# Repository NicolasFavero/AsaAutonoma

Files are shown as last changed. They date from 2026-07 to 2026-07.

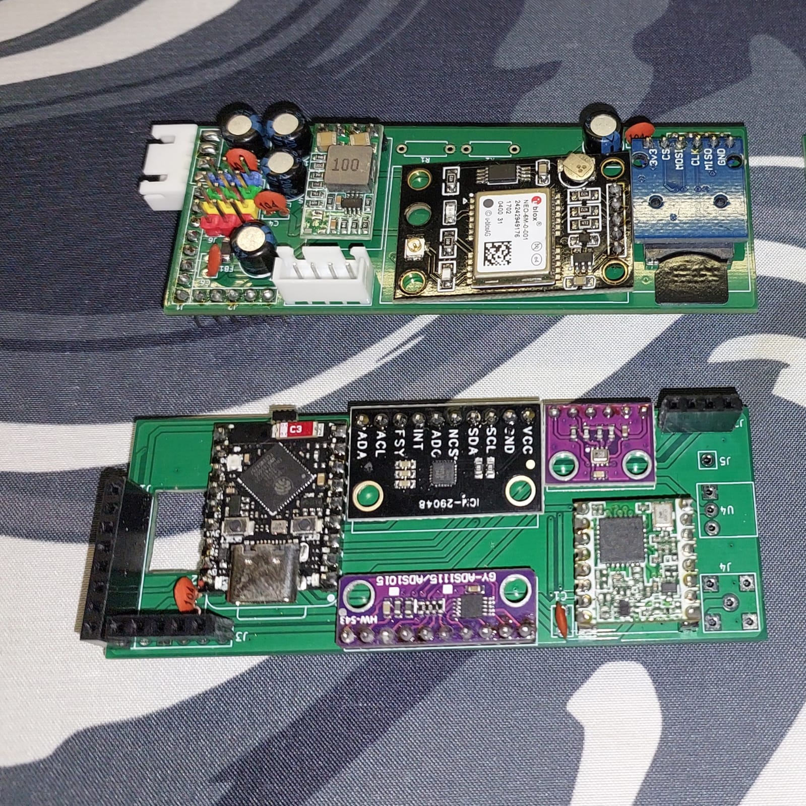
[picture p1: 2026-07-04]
media/image2.jpeg

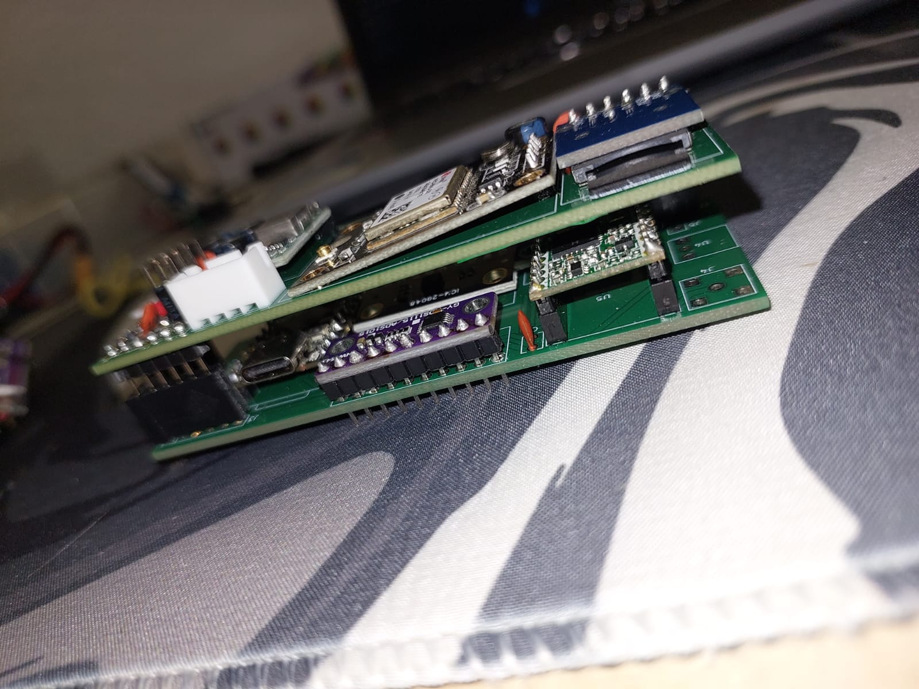
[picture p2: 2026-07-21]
media/image4.jpeg

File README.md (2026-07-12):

# Sistema de Controle e Telemetria para Aeromodelo Autônomo

## Sobre o projeto

Este projeto consiste no desenvolvimento de um **sistema embarcado de controle, navegação e telemetria para uma asa autônoma / aeromodelo planador experimental**.

O sistema é baseado em um **ESP32-S3** e tem como finalidade realizar a aquisição de dados de voo, processamento de sensores, controle das superfícies móveis da aeronave e armazenamento das informações para análise posterior.

O projeto encontra-se em fase de **protótipo e desenvolvimento**, sendo utilizado para testes de hardware, sensores, algoritmos de controle e integração de sistemas embarcados.

---

## Objetivo

Desenvolver uma plataforma experimental para estudo e implementação de um sistema de controle autônomo para aeronaves de pequeno porte, integrando:

* Sensoriamento inercial e ambiental;
* Controle eletrônico das superfícies de comando;
* Registro de dados de voo;
* Desenvolvimento de firmware embarcado;
* Testes e validação de sistemas aplicados à aviação experimental.

---

## Funcionalidades

* Leitura de sensores inerciais:

  * Aceleração;
  * Velocidade angular;
  * Campo magnético;
* Medição de altitude e pressão atmosférica utilizando BMP280;
* Leitura de velocidade do ar através de tubo de Pitot;
* Controle das superfícies de comando:

  * Leme;
  * Aileron;
  * Profundor;
* Controle de servomotores;
* Registro de dados de voo em cartão SD;
* Estrutura preparada para futuras expansões, como telemetria e algoritmos de controle autônomo.

---

## Status do projeto

🚧 **Protótipo em desenvolvimento**

O firmware e o hardware ainda estão em fase experimental. Alterações na arquitetura, sensores utilizados e funcionalidades podem ocorrer durante o desenvolvimento.

---

## Tecnologias utilizadas

### Hardware

* ESP32-S3 SuperMini;
* ICM-20948 (IMU 9DOF);
* BMP280 (pressão e altitude);
* Tubo de Pitot;
* Servomotores;
* Cartão SD.

### Software

* C / C++;
* PlatformIO;
* Arduino Framework.

---

## Dependências

```ini
lib_deps =
	sparkfun/SparkFun 9DoF IMU Breakout - ICM 20948 - Arduino Library@^1.3.2
	adafruit/Adafruit ADS1X15@^2.6.2
	adafruit/Adafruit BMP280 Library@^3.0.0
	mikalhart/TinyGPSPlus@^1.1.0
	greiman/SdFat@^2.3.1
	jgromes/RadioLib@^7.7.1
```

---

## Ambiente de desenvolvimento

* IDE: PlatformIO;
* Framework: Arduino;
* Placa alvo: ESP32-S3 SuperMini.

---

## Estrutura do projeto

```
Firmware/
├── src/
├── include/
├── lib/
└── platformio.ini
```

---

## Aplicação

Projeto desenvolvido para fins educacionais e experimentais, integrando conhecimentos de **eletrônica, programação embarcada, sensores, controle e sistemas aeronáuticos** dentro de uma formação técnica em eletrônica.

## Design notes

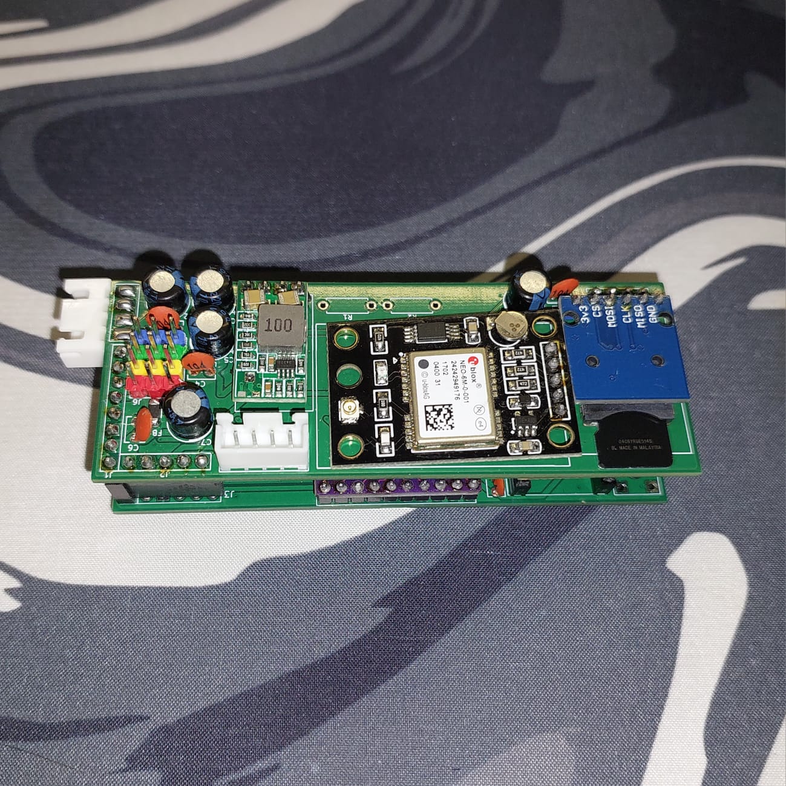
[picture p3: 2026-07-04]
Firmware/midia/midia2.jpeg

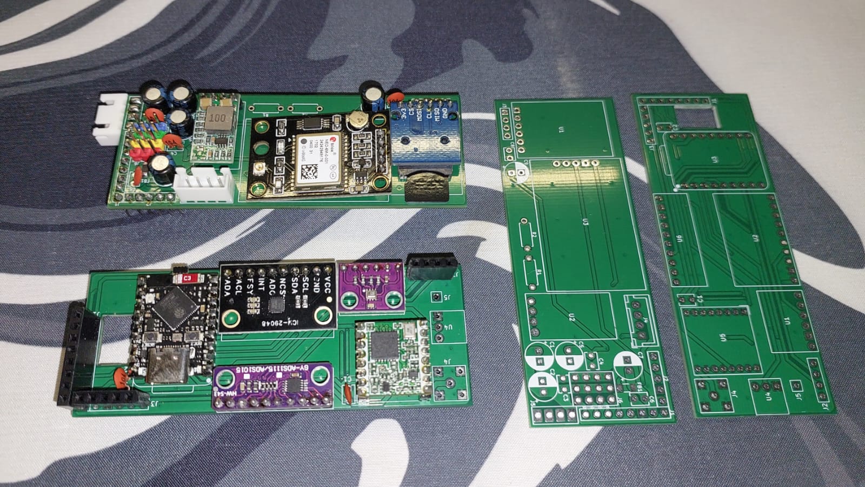
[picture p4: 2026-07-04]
Firmware/midia/midia4.jpeg

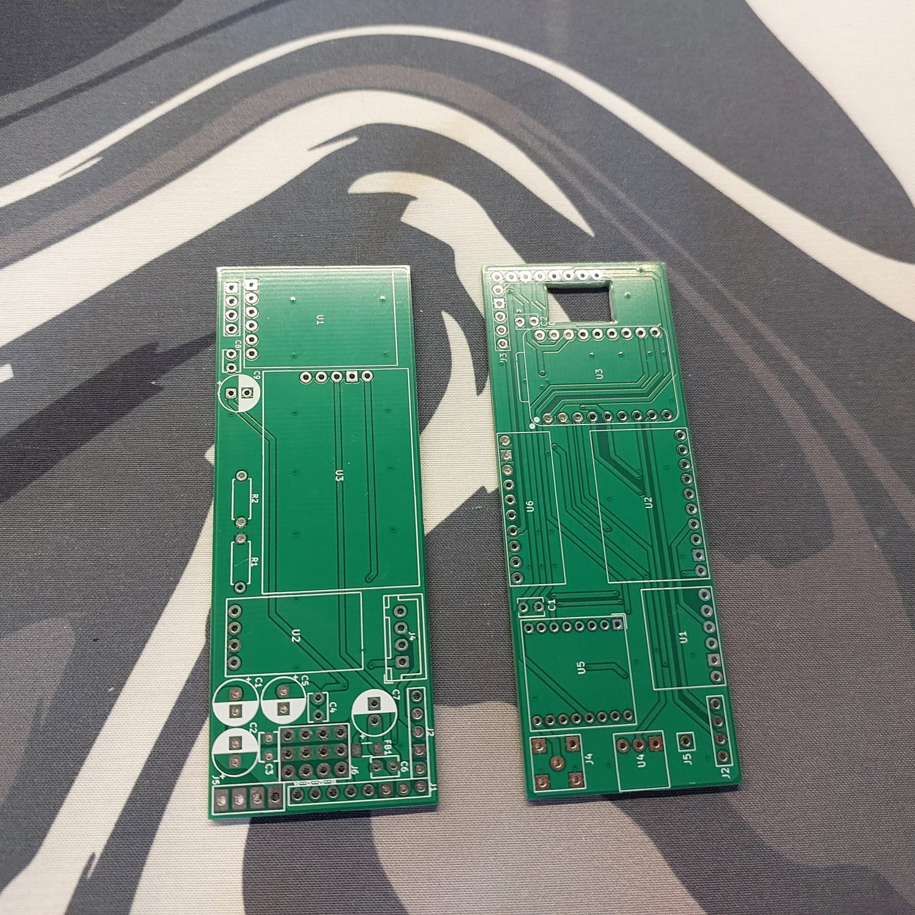
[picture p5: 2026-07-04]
Firmware/midia/midia3.jpeg

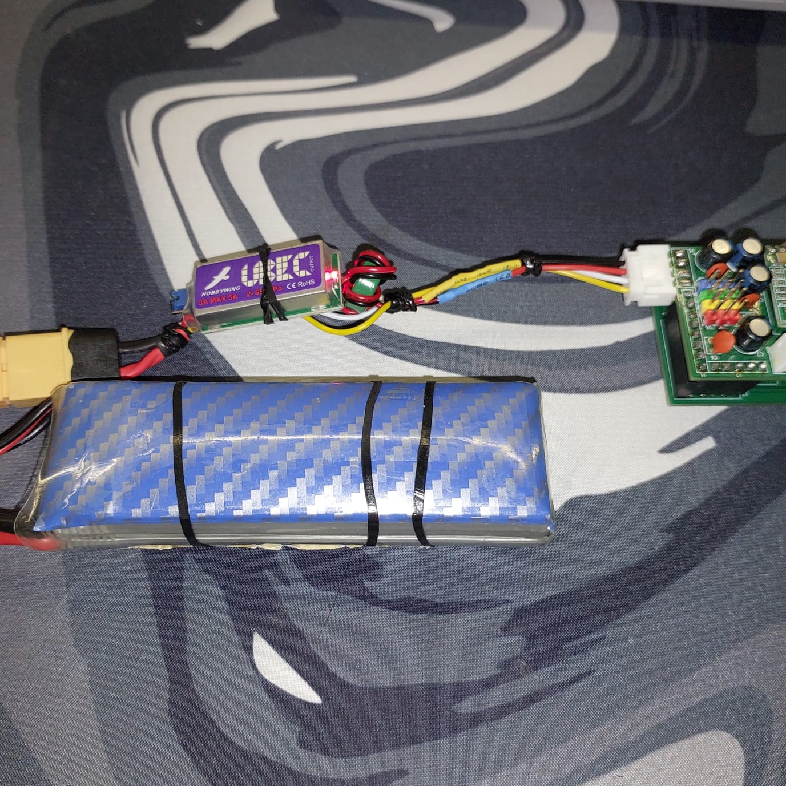
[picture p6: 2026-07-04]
Firmware/midia/midia5.jpeg

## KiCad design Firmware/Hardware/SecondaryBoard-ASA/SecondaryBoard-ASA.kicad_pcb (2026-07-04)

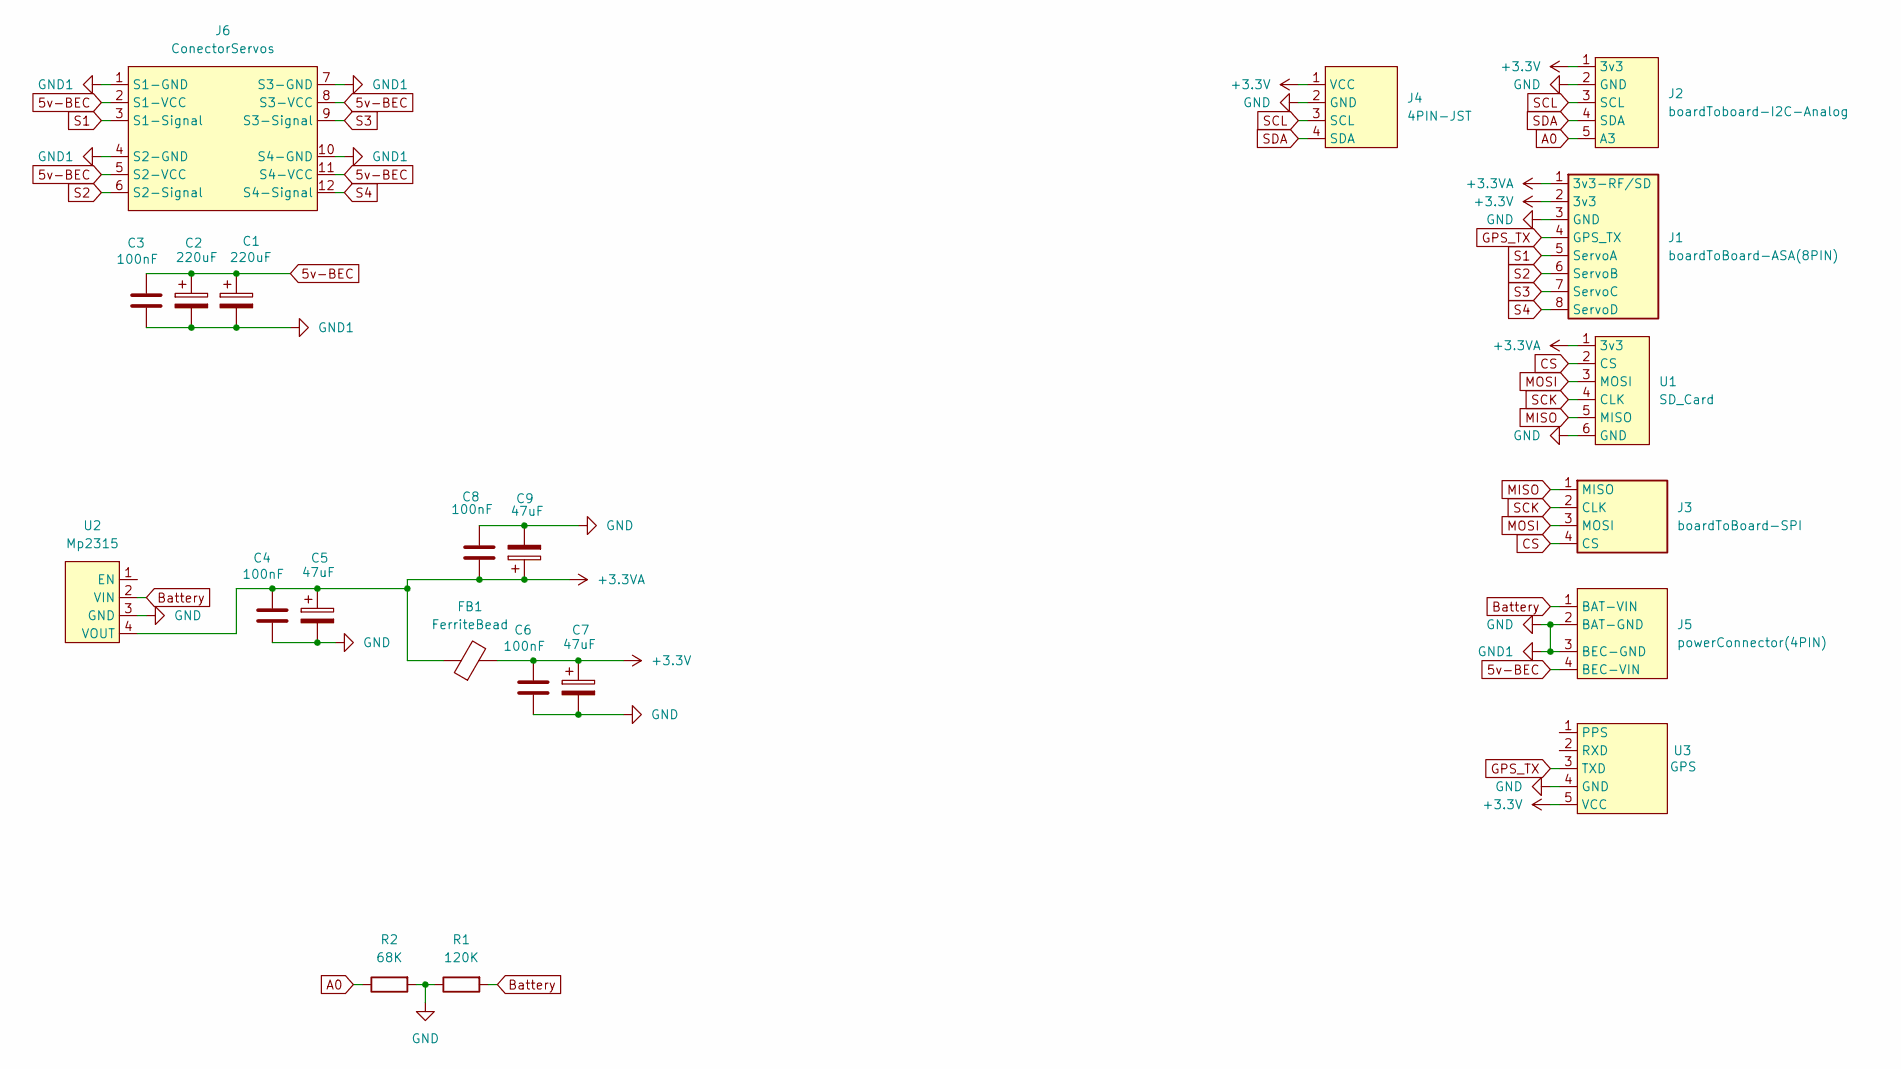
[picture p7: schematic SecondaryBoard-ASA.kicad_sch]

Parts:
C1, C2: 220uF; CP_Radial_D6.3mm_P2.50mm
C3, C4, C6, C8: 100nF; C_Disc_D3.8mm_W2.6mm_P2.50mm
C5, C7, C9: 47uF; CP_Radial_D6.3mm_P2.50mm
FB1: FerriteBead; R_1206_3216Metric_Pad1.30x1.75mm_HandSolder
J1: boardToBoard-ASA(8PIN); PinSocket_1x08_P2.54mm_Vertical
J2: boardToboard-I2C-Analog; PinHeader_1x05_P2.54mm_Vertical
J3: boardToBoard-SPI; PinHeader_1x04_P2.54mm_Vertical
J4: 4PIN-JST; JST_XH_B4B-XH-A_1x04_P2.50mm_Vertical
J5: powerConnector(4PIN); ConnectorBaterry+BEC
J6: ConectorServos; 4Servos
R1: 120K; R_Axial_DIN0207_L6.3mm_D2.5mm_P7.62mm_Horizontal
R2: 68K; R_Axial_DIN0207_L6.3mm_D2.5mm_P7.62mm_Horizontal
U1: SD_Card
U2: Mp2315
U3: GPS

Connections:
5v-BEC: C1.1, C2.1, C3.1, J5.4 (BEC-VIN), J6.2 (S1-VCC), J6.5 (S2-VCC), J6.8 (S3-VCC), J6.11 (S4-VCC)
+3.3V: C6.1, C7.1, FB1.2, J1.2 (3v3), J2.1 (3v3), J4.1 (VCC), U3.5 (VCC)
+3.3VA: C4.1, C5.1, C8.1, C9.1, FB1.1, J1.1 (3v3-RF/SD), U1.1 (3v3), U2.4 (VOUT)
A0: J2.5 (A3), R2.1
Battery: J5.1 (BAT-VIN), R1.2, U2.2 (VIN)
CS: J3.4 (CS), U1.2 (CS)
GND: C1.2, C2.2, C3.2, C4.2, C5.2, C6.2, C7.2, C8.2, C9.2, J1.3 (GND), J2.2 (GND), J4.2 (GND), J5.2 (BAT-GND), J5.3 (BEC-GND), J6.1 (S1-GND), J6.4 (S2-GND), J6.7 (S3-GND), J6.10 (S4-GND), R1.1, R2.2, U1.6 (GND), U2.3 (GND), U3.4 (GND)
GPS_TX: J1.4 (GPS_TX), U3.3 (TXD)
MISO: J3.1 (MISO), U1.5 (MISO)
MOSI: J3.3 (MOSI), U1.3 (MOSI)
S1: J1.5 (ServoA), J6.3 (S1-Signal)
S2: J1.6 (ServoB), J6.6 (S2-Signal)
S3: J1.7 (ServoC), J6.9 (S3-Signal)
S4: J1.8 (ServoD), J6.12 (S4-Signal)
SCK: J3.2 (CLK), U1.4 (CLK)
SCL: J2.3 (SCL), J4.3 (SCL)
SDA: J2.4 (SDA), J4.4 (SDA)

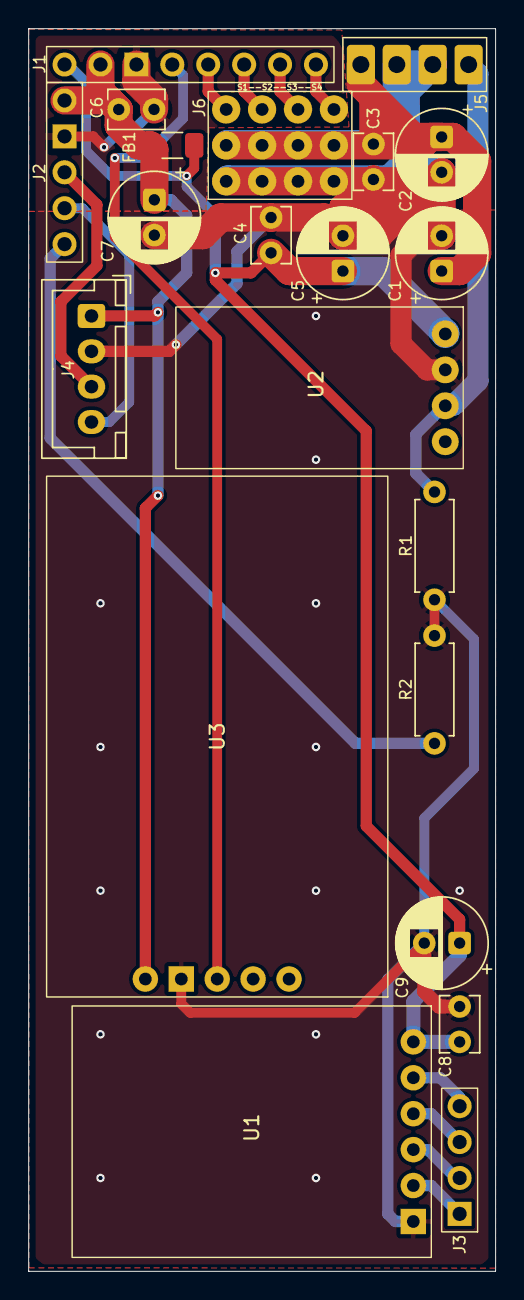
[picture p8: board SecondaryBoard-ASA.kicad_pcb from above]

Board: 2 copper layers, 33.0 x 87.9 mm, 21 parts (0 on the bottom side), 17 nets.

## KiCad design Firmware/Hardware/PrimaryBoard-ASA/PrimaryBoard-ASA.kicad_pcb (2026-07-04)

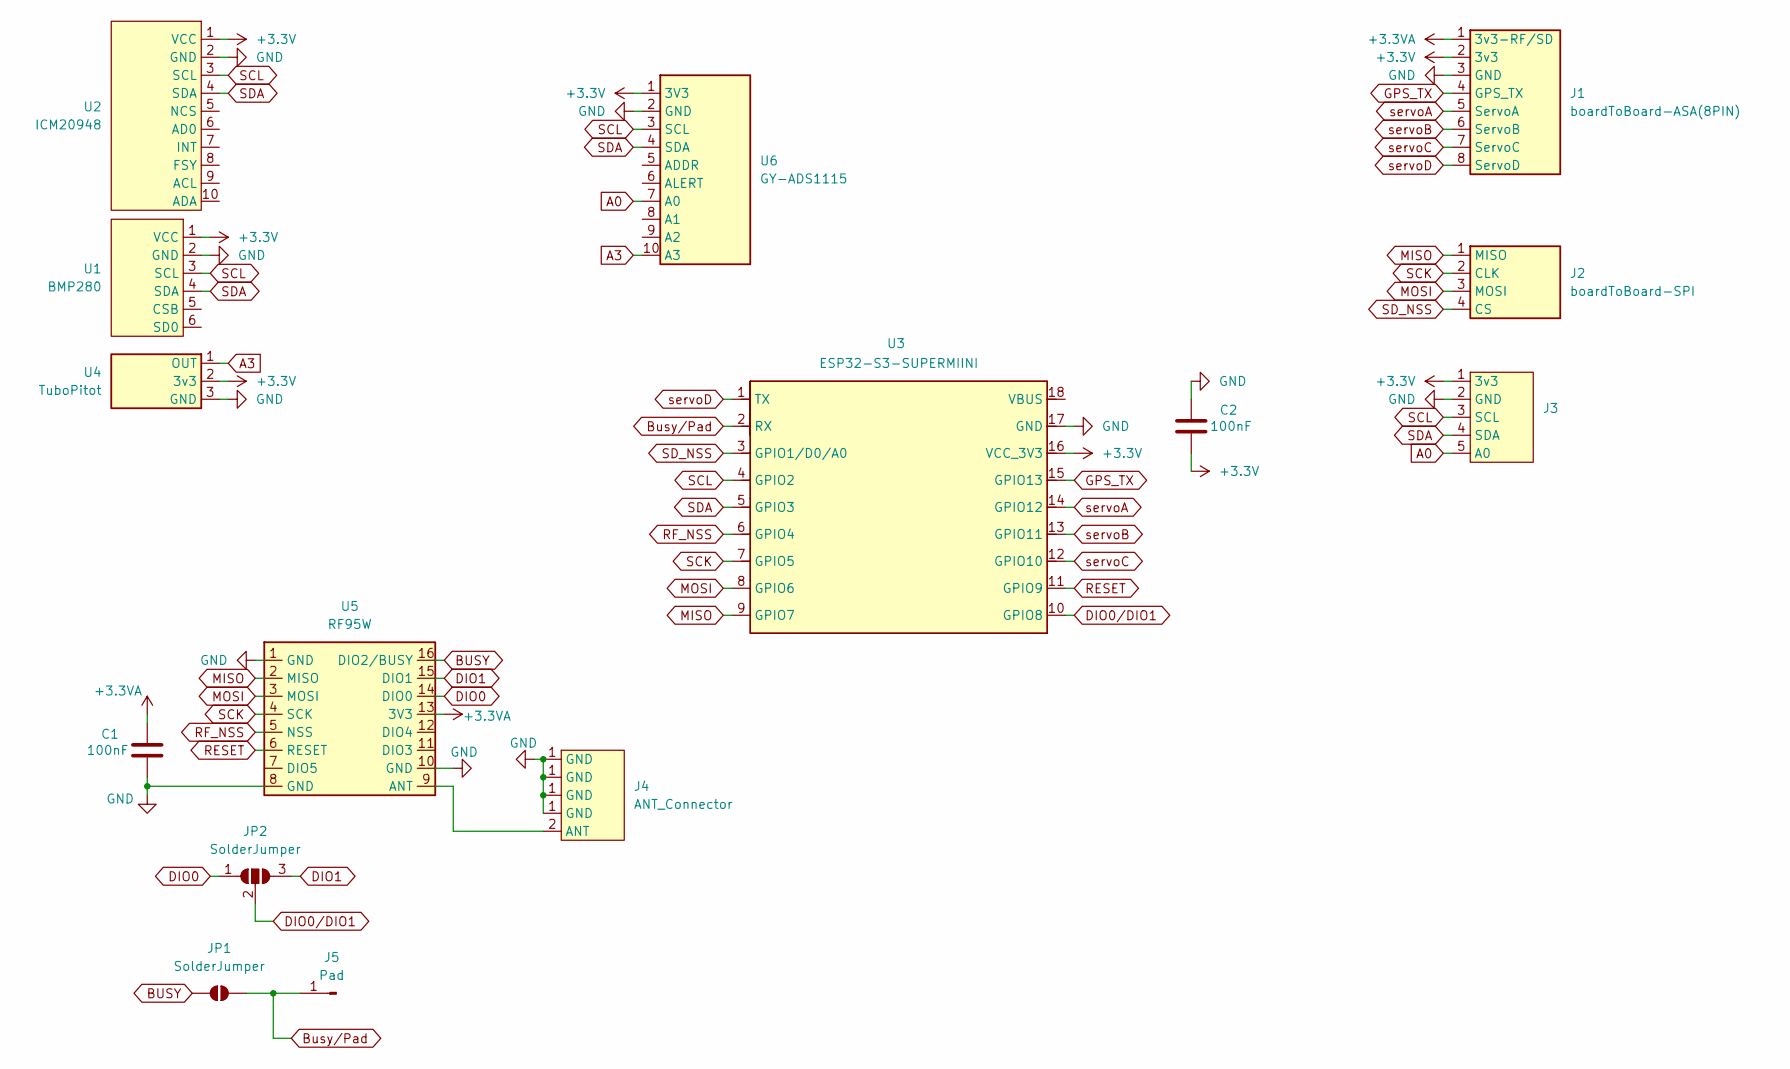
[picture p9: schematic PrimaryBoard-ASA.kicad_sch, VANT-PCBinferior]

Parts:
C1, C2: 100nF; C_Disc_D3.8mm_W2.6mm_P2.50mm
J1: boardToBoard-ASA(8PIN); PinHeader_1x08_P2.54mm_Vertical
J2: boardToBoard-SPI; PinHeader_1x04_P2.54mm_Vertical
J3: PinHeader_1x05_P2.54mm_Vertical
J4: ANT_Connector; conectorAntena2.54mm
J5: Pad; PinHeader_1x01_P2.54mm_Vertical
JP1: SolderJumper; SolderJumper-2_P1.3mm_Open_RoundedPad1.0x1.5mm
JP2: SolderJumper; SolderJumper-3_P1.3mm_Open_RoundedPad1.0x1.5mm
U1: BMP280
U2: ICM20948; ICM 20948
U3: ESP32-S3-SUPERMIINI; myEsp32-S3-Mini
U4: TuboPitot; tuboPitot
U5: RF95W; rf96w
U6: GY-ADS1115; ads1115

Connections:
+3.3V: C2.1, J1.2 (3v3), J3.1 (3v3), U1.1 (VCC), U2.1 (VCC), U3.16 (VCC_3V3), U4.2 (3v3), U6.1 (3V3)
+3.3VA: C1.2, J1.1 (3v3-RF/SD), U5.13 (3V3)
A0: J3.5 (A0), U6.7 (A0)
A3: U4.1 (OUT), U6.10 (A3)
BUSY: JP1.1 (A), U5.16 (DIO2/BUSY)
Busy/Pad: J5.1, JP1.2 (B), U3.2 (RX)
DIO0: JP2.1 (A), U5.14 (DIO0)
DIO0/DIO1: JP2.2 (C), U3.10 (GPIO8)
DIO1: JP2.3 (B), U5.15 (DIO1)
GND: C1.1, C2.2, J1.3 (GND), J3.2 (GND), J4.1 (GND), U1.2 (GND), U2.2 (GND), U3.17 (GND), U4.3 (GND), U5.1 (GND), U5.8 (GND), U5.10 (GND), U6.2 (GND)
GPS_TX: J1.4 (GPS_TX), U3.15 (GPIO13)
MISO: J2.1 (MISO), U3.9 (GPIO7), U5.2 (MISO)
MOSI: J2.3 (MOSI), U3.8 (GPIO6), U5.3 (MOSI)
unnamed: J4.2 (ANT), U5.9 (ANT)
RESET: U3.11 (GPIO9), U5.6 (RESET)
RF_NSS: U3.6 (GPIO4), U5.5 (NSS)
SCK: J2.2 (CLK), U3.7 (GPIO5), U5.4 (SCK)
SCL: J3.3 (SCL), U1.3 (SCL), U2.3 (SCL), U3.4 (GPIO2), U6.3 (SCL)
SDA: J3.4 (SDA), U1.4 (SDA), U2.4 (SDA), U3.5 (GPIO3), U6.4 (SDA)
SD_NSS: J2.4 (CS), U3.3 (GPIO1/D0/A0)
servoA: J1.5 (ServoA), U3.14 (GPIO12)
servoB: J1.6 (ServoB), U3.13 (GPIO11)
servoC: J1.7 (ServoC), U3.12 (GPIO10)
servoD: J1.8 (ServoD), U3.1 (TX)

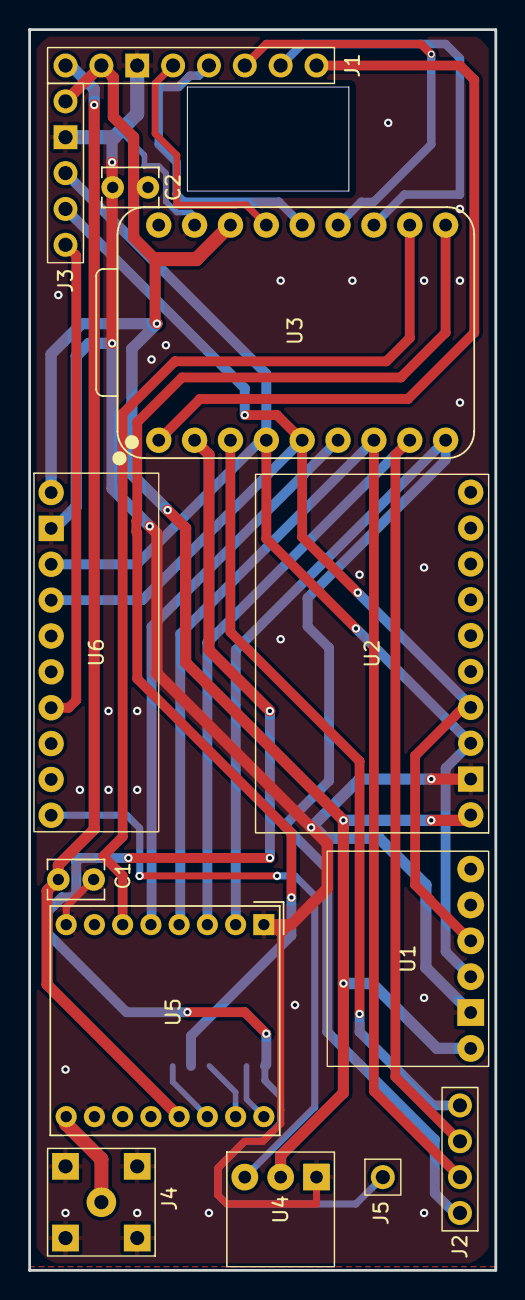
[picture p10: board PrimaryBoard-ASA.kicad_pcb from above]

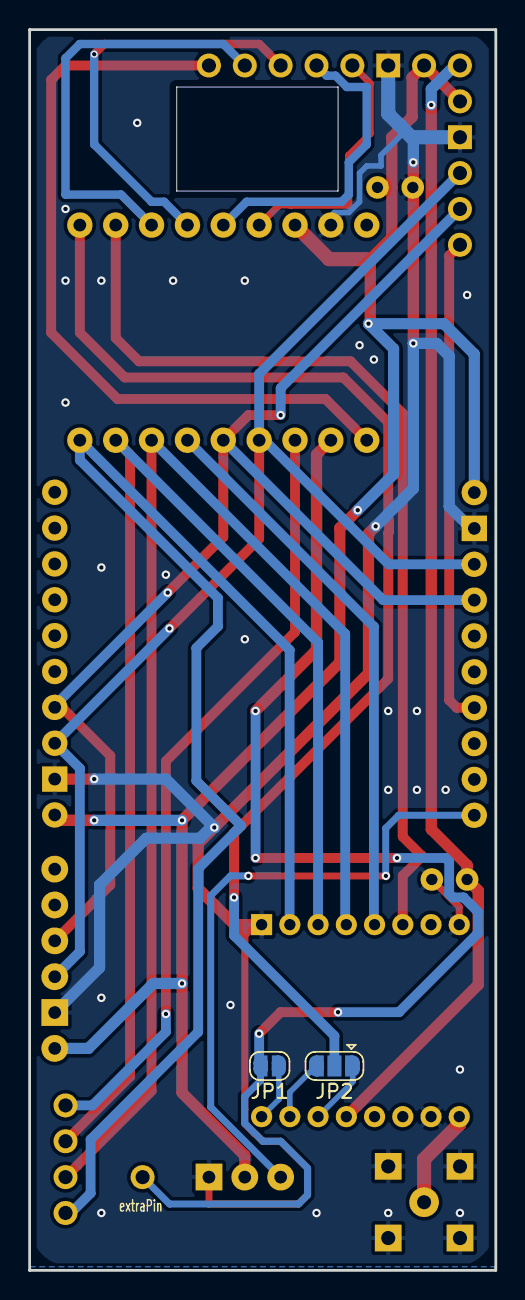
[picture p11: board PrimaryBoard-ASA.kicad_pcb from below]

Board: 2 copper layers, 33.0 x 87.9 mm, 15 parts (2 on the bottom side), 24 nets.

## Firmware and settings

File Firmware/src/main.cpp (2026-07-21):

// Arduino
#include "Arduino.h"

// Config
#include "Pins.h"
#include "ServomotorConfig.h"
#include "DataTypes.h"
#include "CurrentConfig.h"

// Drivers
#include "IMU.h"
#include "GPS.h"
#include "BMP280.h"
#include "ADS1X15.h"

// Communication
#include "RF96W.h"
#include "WiFiAP.h"

// Storage
#include "SdLogger.h"
#include "PreferencesManager.h"

// Control
#include "PID.h"
#include "Servo.h"

// Telemetry
#include "Telemetry.h" //ALTEREI PRA DEBUG     float pitch = imuValid ? attitude.pitch : 0.0f; LEMBRAR DE VOLTAR ATRAS DEPOIS!!!!!!!!!!!!!!!

// Debug
#include "Led.h"
//=======================================================================================================================================================
//OTHERS
unsigned long lastTelemetryMillis = 0;
unsigned long countdownStartMillis = 0;
constexpr unsigned long COUNTDOWN_DURATION_MS = 10000; // mesmo valor do COUNTDOWN_DURATION_S no script.js
volatile bool newOffsetsAvailable = false;
volatile bool newPidAvailable = false;

bool wifiEnabled = false;
bool wifiTemporary = false;

unsigned long wifiStartMillis = 0;
//==================================================================STRUCTS===============================================================================
ImuOffsets currentOffsets; 
PidConfig currentPidConfig;
SystemConfig systemConfig;
SystemStatus systemStatus;
//========================================================================================================================================================
//==================================================================CLASSES==============================================================================
// Drivers
IMU imu;
ADS ads;
BMP280 bmp;
GPS gps(Pins::GPS_TX);

// Communication
LoRa lora(Pins::LORA_CS, Pins::LORA_DIO0, Pins::LORA_RESET, systemConfig.lora);
WifiAP wifi;

// Storage
SdLogger sd(Pins::SD_CS);
PreferencesManager nvs;

// Control
PID pid;

// Actuators
Servo elevator    (Pins::ELEVATOR,      ServoConfig::Channel::ELEVATOR,      ServoConfig::FREQUENCY, ServoConfig::RESOLUTION);
Servo leftAlieron (Pins::LEFT_AILERON,  ServoConfig::Channel::LEFT_AILERON,  ServoConfig::FREQUENCY, ServoConfig::RESOLUTION);
Servo rightAlieron(Pins::RIGHT_AILERON, ServoConfig::Channel::RIGHT_AILERON, ServoConfig::FREQUENCY, ServoConfig::RESOLUTION);
//Servo rudder    (Pins::RUDDER,        ServoConfig::Channel::RUDDER,        ServoConfig::FREQUENCY, ServoConfig::RESOLUTION); 

// Telemetry
Telemetry telemetry;

//Visual Debug
Led led;

//========================================================================================================================================================
//==============================================================FREEERTOS QUEUES===============================================================================
QueueHandle_t attitudeQueue;
QueueHandle_t navigationQueue;
portMUX_TYPE offsetMux = portMUX_INITIALIZER_UNLOCKED;
portMUX_TYPE pidMux = portMUX_INITIALIZER_UNLOCKED;
//========================================================================================================================================================
//=================================================================PROTOTYPES=============================================================================
// TASKS
void taskControl(void *pv);
void taskData(void *pv);

// TASK CONTROL HELPERS
bool readAttitudeData(AttitudeData& attitude);

// TASK DATA HELPERS
void sendNavigationData(NavigationData& navigationData);
void handleWifiTimeout();
void handleOutputs(FlightMode mode);
void handleWifi(const AttitudeData& attitude, const NavigationData& navigationData);
void updateGpsStatus();
void setupWifi();
TelemetryData buildTelemetryData(AttitudeData& attitude);
// GENERAL HELPERS
bool isLowPowerModeEnabled();

//=========================================================================================================================================================
//===================================================================SETUP=================================================================================
void setup(){
  Serial.begin(115200);
  Serial.println("Beginning...");
  Wire.begin(Pins::SDA, Pins::SCL);
  Wire.setClock(400000); 

  SPI.begin(Pins::SCK, Pins::MISO, Pins::MOSI);

  led.white();
  //led.white();

  nvs.loadSystem(systemConfig);
  nvs.loadOffsets(currentOffsets);
  nvs.loadPid(currentPidConfig);

  // Sem isso, o offset salvo nas Preferences so era realmente
  // aplicado no calculo do angulo (localOffsets, dentro da task de
  // controle) depois que o usuario salvasse um offset pela web --
  // ate la, localOffsets ficava zerado mesmo com currentOffsets/
  // /api/status ja reportando o valor salvo do boot anterior. Isso
  // fazia a primeira tara depois de ligar somar o offset antigo (que
  // NAO estava de fato sendo subtraido da leitura) com o novo valor
  // calculado, dando um offset errado logo na primeira vez -- so
  // acertava no segundo, quando o evento OFFSET_CHANGED sincronizava
  // localOffsets pela primeira vez. Marcando newOffsetsAvailable aqui,
  // a task de controle sincroniza localOffsets = currentOffsets logo
  // na primeira iteracao do loop, antes de qualquer leitura ser usada.
  newOffsetsAvailable = true;

  pid.pitch.kp = currentPidConfig.pitch.kp;
  pid.pitch.ki = currentPidConfig.pitch.ki;
  pid.pitch.kd = currentPidConfig.pitch.kd;

  pid.roll.kp = currentPidConfig.roll.kp;
  pid.roll.ki = currentPidConfig.roll.ki;
  pid.roll.kd = currentPidConfig.roll.kd;

  pid.yaw.kp = currentPidConfig.yaw.kp;
  pid.yaw.ki = currentPidConfig.yaw.ki;
  pid.yaw.kd = currentPidConfig.yaw.kd;

  while(!imu.begin()){led.red();}
  while(!bmp.begin()){led.red();}
  while(!gps.begin()){led.red();}
  while(!ads.begin()){led.red();}
  while(!lora.begin()){led.red();}

  while(!elevator.begin()){led.red();}
  while(!leftAlieron.begin()){led.red();}
  while(!rightAlieron.begin()){led.red();}


  while(!sd.begin()) {Serial.println("SD FAIL"); led.red();}

  // Buffer em RAM/PSRAM pros logs de voo -- ver comentarios em
  // SdLogger::beginBuffer()/bufferLine(). Se falhar (placa sem PSRAM
  // ou sem RAM livre suficiente), o firmware continua funcionando,
  // so volta a escrever direto no SD a cada leitura como antes.
  sd.beginBuffer();

  attitudeQueue = xQueueCreate(1, sizeof(AttitudeData));
  navigationQueue = xQueueCreate(1, sizeof(NavigationData));

  if(attitudeQueue == NULL || navigationQueue == NULL){
    while(true){
      led.red();
      delay(500);
    }
  }
  setupWifi();

  lastTelemetryMillis = millis();

  led.green();
  
  xTaskCreatePinnedToCore(
    taskControl,
    "Control",
    10000,
    NULL,
    2,
    NULL,
    0
  );
  xTaskCreatePinnedToCore(
    taskData,
    "Data",
    10000,
    NULL,
    1,
    NULL,
    1
  );
}
//==========================================================================================================================================================
//================================================================KILLING TASK==============================================================================
void loop(){vTaskDelete(NULL);}
//==========================================================================================================================================================
//=================================================================TASK AT CORE 0===========================================================================
void taskControl(void *pv){

  TickType_t lastWake = xTaskGetTickCount();
  const TickType_t period = pdMS_TO_TICKS(5); //200HZ

  while(true){
    bool useNewValues = true;

    static AttitudeData attitudeData;
    static NavigationData nav; 
    static ServoPositions angle;
    static ImuOffsets localOffsets; 
  //===================TO  ATTITUDE==============
    if(systemConfig.flightMode == FlightMode::CONFIG && newOffsetsAvailable){
      portENTER_CRITICAL(&offsetMux);

      localOffsets = currentOffsets;

      newOffsetsAvailable = false;

      portEXIT_CRITICAL(&offsetMux);
    }

    if(systemConfig.flightMode == FlightMode::CONFIG && newPidAvailable){
      portENTER_CRITICAL(&pidMux);

      pid.pitch.kp = currentPidConfig.pitch.kp;
      pid.pitch.ki = currentPidConfig.pitch.ki;
      pid.pitch.kd = currentPidConfig.pitch.kd;

      pid.roll.kp = currentPidConfig.roll.kp;
      pid.roll.ki = currentPidConfig.roll.ki;
      pid.roll.kd = currentPidConfig.roll.kd;

      pid.yaw.kp = currentPidConfig.yaw.kp;
      pid.yaw.ki = currentPidConfig.yaw.ki;
      pid.yaw.kd = currentPidConfig.yaw.kd;

      newPidAvailable = false;

      portEXIT_CRITICAL(&pidMux);
    }

    imu.update();

    if(systemConfig.flightMode == FlightMode::FLIGHT){
      pid.setAngles(angle, attitudeData, nav, useNewValues);
    }


    elevator.write(angle.elevator);
    leftAlieron.write(angle.leftAileron);
    rightAlieron.write(angle.rightAileron);

  //===================TO  ATTITUDE==============
  //=====================FOR SEND================
    attitudeData.pitch = imu.getPitch() - localOffsets.pitch;
    attitudeData.roll = imu.getRoll() - localOffsets.roll;
    attitudeData.yaw = imu.getYaw() - localOffsets.yaw;

    // Mesmo valor que acabou de ir pro elevator.write()/leftAlieron.write()/
    // rightAlieron.write() acima -- registrado aqui, e nao lido de volta do
    // servo, porque servo (PWM) nao tem telemetria de posicao real.
    attitudeData.servoElevator = angle.elevator;
    attitudeData.servoLeftAileron = angle.leftAileron;
    attitudeData.servoRightAileron = angle.rightAileron;

    attitudeData.accX = imu.getAccX();
    attitudeData.accY = imu.getAccY();
    attitudeData.accZ = imu.getAccZ();

    attitudeData.gyroX = imu.getGyroX();
    attitudeData.gyroY = imu.getGyroY();
    attitudeData.gyroZ = imu.getGyroZ();

    attitudeData.magX= imu.getMagX();
    attitudeData.magY = imu.getMagY();
    attitudeData.magZ = imu.getMagZ();

    attitudeData.isImuOk = imu.isHealthy();

    xQueueOverwrite(attitudeQueue, &attitudeData);
  //=====================FOR SEND================
  //====================TO  RECEIVE==============
    if(xQueueReceive(navigationQueue,&nav,0)){useNewValues = true;}
  //====================TO  RECEIVE==============
  
    vTaskDelayUntil(&lastWake,period);
  }
}
//==========================================================================================================================================================
//=================================================================TASK AT CORE 1===========================================================================
void taskData(void *pv){

  TickType_t lastWake = xTaskGetTickCount();
  const TickType_t period = pdMS_TO_TICKS(100); //10HZ
  static bool isImuValid = false;

  while(true){

    static NavigationData navigationData;
    static AttitudeData attitude;

    readAttitudeData(attitude);

    systemStatus.bmpOk = bmp.update();
    systemStatus.imuOk = attitude.isImuOk;

    if(gps.update()){led.green(); /*Serial.println("GPS Atualizado");*/} 
    else{led.blue();}

    if(systemConfig.flightMode == FlightMode::COUNTDOWN){

        unsigned long elapsed = millis() - countdownStartMillis;

        if(elapsed >= COUNTDOWN_DURATION_MS){
            systemConfig.flightMode = FlightMode::FLIGHT;
            wifi.setFlightMode(systemConfig.flightMode);
            wifi.setCountdownRemaining(0);
        }
        else{
            wifi.setCountdownRemaining(COUNTDOWN_DURATION_MS - elapsed);
        }
    }
    else{
        wifi.setCountdownRemaining(0);
    }

    telemetry.update(buildTelemetryData(attitude));

    sendNavigationData(navigationData);

    handleOutputs(systemConfig.flightMode);//Sends LoRa Packets and registers logs in SD_Card, it update systemStatus.loraOk

    // Modo de voo "WiFi": o unico modo por enquanto mantem o WiFi
    // ativo mesmo durante o FLIGHT, entao o AP continua respondendo
    // (status, Finalizar Voo, telemetria) em vez de ficar mudo ate
    // o pouso. Logs no SD e envio LoRa continuam de qualquer forma,
    // isso e controlado em handleOutputs().
    if(wifiEnabled){
      handleWifi(attitude, navigationData);
      updateGpsStatus();
    }
    else{
      handleWifiTimeout();
    }

    vTaskDelayUntil(&lastWake, period);
  }
}
//==========================================================================================================================================================
//================================================================OTHERS FUNCTIONS==========================================================================
void handleWifi(const AttitudeData& attitude, const NavigationData& navigationData){
    if(!systemConfig.wifiEnabled)
        return;

    wifi.update();

    wifi.setAttitude(attitude);

    wifi.setNavigation(navigationData);

    wifi.setSystemStatus(systemStatus);

    switch(wifi.getPendingEvent())
    {
        case SystemEvent::NONE:
            return;

        case SystemEvent::OFFSET_CHANGED:

            portENTER_CRITICAL(&offsetMux);

            currentOffsets = wifi.getOffsets();

            newOffsetsAvailable = true;

            portEXIT_CRITICAL(&offsetMux);

            nvs.saveOffsets(currentOffsets);

            wifi.setOffsets(currentOffsets);

            break;

        case SystemEvent::PID_CHANGED:

            portENTER_CRITICAL(&pidMux);

            currentPidConfig = wifi.getPidConfig();

            newPidAvailable = true;

            portEXIT_CRITICAL(&pidMux);

            nvs.savePid(currentPidConfig);

            wifi.setPidConfig(currentPidConfig);

            break;

        case SystemEvent::SYSTEM_CHANGED:

            systemConfig = wifi.getSystemConfig();

            nvs.saveSystem(systemConfig);

            wifi.setSystemConfig(systemConfig);

            break;

        case SystemEvent::LORA_CHANGED:

            systemConfig = wifi.getSystemConfig();

            nvs.saveLora(systemConfig.lora);

            lora.reconfigure(systemConfig.lora);

            wifi.setSystemConfig(systemConfig);

            break;

        case SystemEvent::START_FLIGHT:

            systemConfig.flightMode =
                FlightMode::COUNTDOWN;

            wifi.setFlightMode(
                systemConfig.flightMode
            );

            sd.createFile();

            {
                // Grava os ganhos de PID que estao REALMENTE em uso
                // (pid.pitch/roll/yaw, o mesmo struct usado dentro de
                // computePID) no inicio do voo, antes do header do
                // CSV -- assim, se um voo se comportar estranho, da
                // pra conferir depois exatamente qual Kp/Ki/Kd estava
                // valendo naquele log, sem depender de lembrar (ou de
                // confiar) qual config estava setada na hora.
                char pidInfoLine[192];

                snprintf(
                    pidInfoLine,
                    sizeof(pidInfoLine),
                    "# PID pitch Kp=%.4f Ki=%.4f Kd=%.4f | roll Kp=%.4f Ki=%.4f Kd=%.4f | yaw Kp=%.4f Ki=%.4f Kd=%.4f",
                    pid.pitch.kp, pid.pitch.ki, pid.pitch.kd,
                    pid.roll.kp,  pid.roll.ki,  pid.roll.kd,
                    pid.yaw.kp,   pid.yaw.ki,   pid.yaw.kd
                );

                sd.bufferLine(pidInfoLine);
            }

            sd.bufferLine(telemetry.getCsvHeader());

            countdownStartMillis = millis();

            break;

        case SystemEvent::END_FLIGHT:

            systemConfig.flightMode =
                FlightMode::LANDED;

            wifi.setFlightMode(
                systemConfig.flightMode
            );

            sd.flushBuffer();
            sd.closeFile();

            break;

        case SystemEvent::DEACTIVATE_FLIGHT:

            systemConfig.flightMode =
                FlightMode::LANDED;

            wifi.setFlightMode(
                systemConfig.flightMode
            );
            sd.flushBuffer();
            sd.closeFile();

            break;

        case SystemEvent::RESET_FLIGHT:

            // Reativa o voo sem precisar reiniciar o ESP32: só
            // permitido a partir de LANDED (checado no
            // handleResetFlight() do WifiAP), volta pra CONFIG e
            // libera offsets/PID/sistema/LoRa pra edicao de novo.
            systemConfig.flightMode =
                FlightMode::CONFIG;

            wifi.setFlightMode(
                systemConfig.flightMode
            );

            break;

        case SystemEvent::CHECK_SD:

            systemStatus.sdOk = sd.selfTest();

            systemStatus.sdTested = true;

            break;

        case SystemEvent::CHECK_LORA:

            systemStatus.loraOk = lora.send(
                "TEST;PING"
            );

            systemStatus.loraTested = true;

            break;

        case SystemEvent::DELETE_ALL_LOGS:

            if(sd.removeAllLogs())
            {
                Serial.println("Todos os logs removidos.");
            }
            else
            {
                Serial.println("Falha ao remover logs.");
            }

            break;
        case SystemEvent::DELETE_LOG:

            if(sd.removeFile(wifi.getRequestedLog()))
            {
                Serial.println("Log removido.");
            }
            else
            {
                Serial.println("Falha ao remover log.");
            }

            break;
        case SystemEvent::RENAME_LOG:

            if(sd.renameFile(wifi.getRequestedLog(), wifi.getRenameTarget()))
            {
                Serial.println("Log renomeado.");
            }
            else
            {
                Serial.println("Falha ao renomear log.");
            }

            break;
        case SystemEvent::TELEMETRY_REQUEST:

            wifi.setTelemetryJson(telemetry.buildLoraPacket(false));

            break;

        case SystemEvent::RESTART:

            ESP.restart();

            return;
    }

    wifi.clearPendingEvent();
}
void handleOutputs(FlightMode mode){

    bool lowPower = isLowPowerModeEnabled();
    uint32_t period = lowPower? systemConfig.lowBatteryTelemetryPeriodMs : systemConfig.telemetryPeriodMs;

    if(FlightMode::CONFIG == mode){

        if(systemConfig.preFlightTelemetryEnabled &&
           millis() - lastTelemetryMillis >= period)
        {
            lastTelemetryMillis = millis();

            systemStatus.loraOk = lora.send(telemetry.buildLoraPacket(lowPower));
        }
    }
    else if(FlightMode::COUNTDOWN == mode || FlightMode::FLIGHT == mode){


        if(millis() - lastTelemetryMillis >= 100){
            
            lastTelemetryMillis = millis();
            systemStatus.sdOk = sd.bufferLine(telemetry.buildCsv());

            if(millis() - lastTelemetryMillis >= period){

                lastTelemetryMillis = millis();
                systemStatus.loraOk = lora.send(telemetry.buildLoraPacket(lowPower));
            }
        }
    }

    else if(FlightMode::LANDED == mode){

        period = systemConfig.lowBatteryTelemetryPeriodMs;
    }
}
void sendNavigationData(NavigationData& navigationData){
    
  const bool gpsValid = gps.isValid();

    navigationData.latitude =
        gpsValid ? gps.getLatitude() : 0.0;

    navigationData.longitude =
        gpsValid ? gps.getLongitude() : 0.0;

    navigationData.gpsAltitude =
        gpsValid ? gps.getAltitude() : 0.0f;

    navigationData.course =
        gpsValid ? gps.getCourse() : 0.0f;

    navigationData.satellites =
        gps.getSatellites();

    navigationData.baroAltitude =
        bmp.getRawAltitude();

    navigationData.temperature =
        bmp.getTemperature();

    navigationData.battery =
        ads.batteryLevel();

    xQueueOverwrite(
        navigationQueue,
        &navigationData
    );
}
bool readAttitudeData(AttitudeData& attitude){
    return xQueueReceive(
        attitudeQueue,
        &attitude,
        0
    ) == pdTRUE;
}
bool isLowPowerModeEnabled(){
    return ads.batteryLevel() < systemConfig.batteryLimit;
}
void updateGpsStatus(){
    if(!gps.hasCommunication())
    {
        systemStatus.gpsStatus = GpsStatus::NO_COMMUNICATION;
        return;
    }

    if(!gps.isValid())
    {
        systemStatus.gpsStatus = GpsStatus::NO_FIX;
        return;
    }

    if(gps.getSatellites() < 6)
    {
        systemStatus.gpsStatus = GpsStatus::POOR_FIX;
        return;
    }

    systemStatus.gpsStatus = GpsStatus::GOOD_FIX;
}
void setupWifi(){
    // Nunca voou: liga normalmente
    /*if(systemConfig.flightMode == FlightMode::CONFIG)
    {
        wifiEnabled = true;
        wifiTemporary = false;
    }
    // Já voou: só liga se detectar 3,3 V no A3
    else if(ads.adcVoltage(3) > 3.0f)
    {
        wifiEnabled = true;
        wifiTemporary = true;
        wifiStartMillis = millis();
    }*/

    //if(!wifiEnabled)
        //return;

    if(wifi.begin())
    {
        wifiEnabled = true;

        wifi.attachSdLogger(&sd);

        wifi.print();

        wifi.setSystemConfig(systemConfig);

        wifi.setOffsets(currentOffsets);

        wifi.setPidConfig(currentPidConfig);
    }
    else
    {
        wifiEnabled = false;
    }
}
void handleWifiTimeout(){
    if(!wifiEnabled || !wifiTemporary)
        return;

    // Se alguém conectou, mantém o AP ligado
    if(wifi.hasClient())
    {
        wifiTemporary = false;
        return;
    }

    // Ninguém conectou durante 20 s
    if(millis() - wifiStartMillis >= 20000)
    {
        wifi.stop();

        wifiEnabled = false;

        wifiTemporary = false;
    }
}
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

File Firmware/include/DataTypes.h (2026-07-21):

#pragma once
#include <Arduino.h>

struct AttitudeData{
    float pitch = 0.0f;
    float roll = 0.0f;
    float yaw = 0.0f;

    // Posicao (em graus) efetivamente mandada pro servo naquele ciclo --
    // ou seja, angle.elevator/leftAileron/rightAileron ja depois do PID +
    // slew-rate + limite de hardware (ver PID::computePID). Fica perto do
    // pitch/roll/yaw de proposito, pra facilitar comparar o angulo lido
    // vs o angulo comandado no mesmo instante.
    float servoElevator = 90.0f;
    float servoLeftAileron = 90.0f;
    float servoRightAileron = 90.0f;

    float accX = 0.0f;
    float accY = 0.0f;
    float accZ = 0.0f;

    float gyroX = 0.0f;
    float gyroY = 0.0f;
    float gyroZ = 0.0f;

    float magX = 0.0f;
    float magY = 0.0f;
    float magZ = 0.0f;

    bool isImuOk = false;
};

struct NavigationData{
    double latitude = 0.0f;
    double longitude = 0.0f;

    float gpsAltitude = 0.0f;
    float course = 0.0f;

    uint8_t satellites = 0;

    float baroAltitude = 0.0f;
    float temperature = 0.0f;
    float battery = 0.0f;
};


struct ServoPositions{
    float elevator =  90.0f;
    float leftAileron = 90.0f;
    float rightAileron = 90.0f;
};


/*==========================================================
                    IMU Offsets
==========================================================*/

struct ImuOffsets
{
    float pitch = 0.0f;
    float roll = 0.0f;
    float yaw = 0.0f;
};

/*==========================================================
                    PID Gains
==========================================================*/

struct PidGains
{
    float kp = 0.0f;
    float ki = 0.0f;
    float kd = 0.0f;
};

struct PidConfig
{
    PidGains pitch;
    PidGains roll;
    PidGains yaw; // Ainda nao usado no controle, mas ja fica pronto.
};

struct LoraConfig
{
    float frequency = 915.0f;

    float bandwidth = 125.0f;

    uint8_t spreadingFactor = 10;

    uint8_t codingRate = 5;

    uint8_t power = 20;

    uint16_t preambleLength = 8;

    uint8_t syncWord = 0x12;
};

enum class FlightMode : uint8_t
{
    CONFIG,
    COUNTDOWN,
    FLIGHT,
    LANDED
};

/*==========================================================
                    GPS Status
==========================================================*/

enum class GpsStatus : uint8_t
{
    NO_COMMUNICATION = 0,   // Vermelho
    NO_FIX           = 1,   // Laranja
    POOR_FIX         = 2,   // Amarelo
    GOOD_FIX         = 3    // Verde
};

enum class SystemEvent : uint8_t{
    NONE,

    OFFSET_CHANGED,
    PID_CHANGED,
    SYSTEM_CHANGED,
    LORA_CHANGED,

    CHECK_SD,
    CHECK_LORA,

    START_FLIGHT,
    END_FLIGHT,
    DEACTIVATE_FLIGHT,
    RESET_FLIGHT,

    DELETE_ALL_LOGS,
    DELETE_LOG,
    RENAME_LOG,

    TELEMETRY_REQUEST,

    RESTART
};
struct SystemConfig
{
    float batteryLimit = 7.5f;

    uint16_t telemetryPeriodMs = 1000;

    uint16_t lowBatteryTelemetryPeriodMs = 10000;

    uint16_t estimatedFlightTimeMin = 30;

    bool wifiEnabled = true;

    bool preFlightTelemetryEnabled = false;

    FlightMode flightMode = FlightMode::CONFIG;

    LoraConfig lora;
};

struct SystemStatus
{
    bool imuOk = false;

    GpsStatus gpsStatus = GpsStatus::NO_COMMUNICATION;

    bool bmpOk = false;

    bool adsOk = false;

    bool loraOk = false;
    bool loraTested = false;

    bool sdOk = false;
    bool sdTested = false;

    bool wifiRunning = false;

    bool wifiClientConnected = false;

    uint8_t wifiClients = 0;
};

struct TelemetryData
{
    bool gpsOk;
    bool imuOk;

    FlightMode state;

    float pitch;
    float roll;
    float yaw;

    // Posicao (graus) mandada pro servo -- ver comentario em AttitudeData.
    float servoElevator;
    float servoLeftAileron;
    float servoRightAileron;

    float accX;
    float accY;
    float accZ;

    float gyroX;
    float gyroY;
    float gyroZ;

    float magX;
    float magY;
    float magZ;

    float latitude;
    float longitude;

    float gpsAltitude;
    float baroAltitude;

    float course;
    float temperature;
    float battery;

    uint8_t satellites;

    uint8_t day;
    uint8_t month;
    uint16_t year;

    uint8_t hour;
    uint8_t minute;
    uint8_t second;
};

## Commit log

2026-07-04 new rep - pcb
    [PrimaryBoard-ASA.kicad_pcb, PrimaryBoard-ASA.kicad_sch, SecondaryBoard-ASA.kicad_pcb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]
2026-07-09 add midia
    [PrimaryBoard-ASA.kicad_sch]
2026-07-11 add lib IMU
2026-07-12 add ADS1115, ICM20948, GPS, BMP280, LED, RF96W, SD, Servo... libs
2026-07-12 Rename for better understanding
    [PrimaryBoard-ASA.kicad_pcb, PrimaryBoard-ASA.kicad_sch, SecondaryBoard-ASA.kicad_pcb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]
2026-07-13 feat: add telemetry library and test sensors
2026-07-13 feat: add PID controller(architecture and organize main with FreeRTOS tasks
2026-07-18 pid, log, telemetry, flight... new web settings
2026-07-18 tracking pid pages
2026-07-18 fix imu status and telemetry bug
    [DataTypes.h]
2026-07-19 fix: PID bug
2026-07-19 change pid
